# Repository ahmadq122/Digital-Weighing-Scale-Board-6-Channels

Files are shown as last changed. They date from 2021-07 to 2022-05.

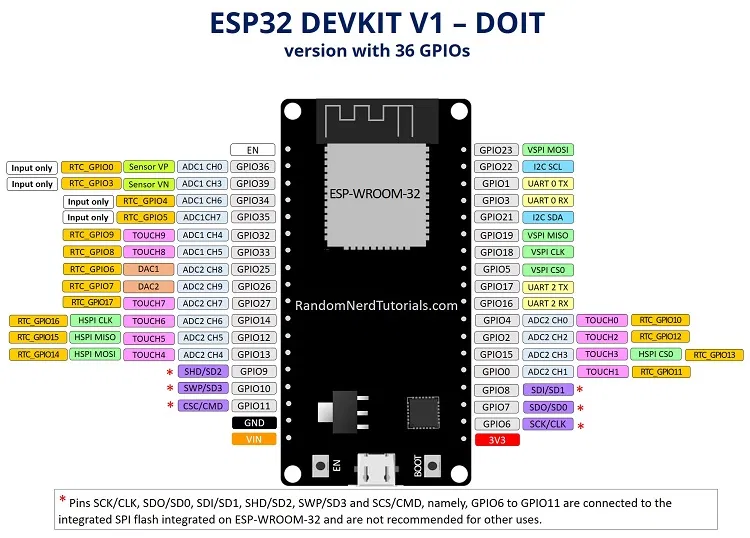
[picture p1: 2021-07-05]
pict/ESP32-DOIT-DEVKIT-V1-Board-Pinout-36-GPIOs-updated.png

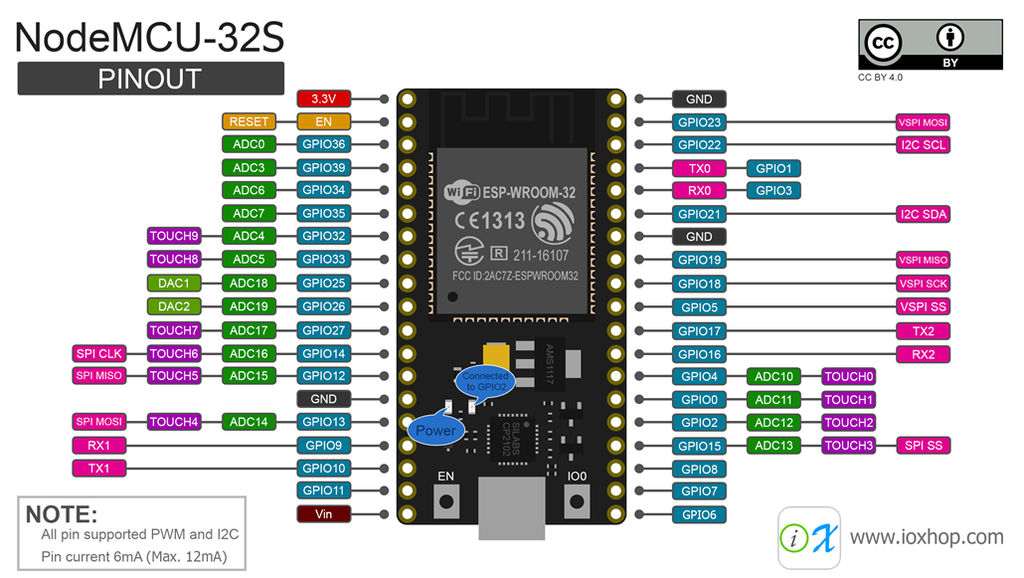
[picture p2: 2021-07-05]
pict/ESP-32S Pin.png

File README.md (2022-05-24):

# Digital-Weighing-Scale-Board-6-Channels
The board uses ESP32 Dev Board as the microcontroller with Nextion 3.2" LCD Touch as a User Interface, made in portable form, and easy to use. Real Time Operating System (FreeRTOS) was applied to get better code structure and device performance. Weighing can be performed on 6 different objects at the same time, with adjustable maximum weighing on each channel. Use 3 pcs of IC ADS1232 as an Analog to Digital Converter. Calibration sensor feature available, with a maximum of 8 calibration points. 3 data logging models are available, which are Local via Micro SD card, Serial RS232, and logging through ThingSpeak.

Code programming is done in IDE: Platform IO - Visual Studio Code Framework: Arduino

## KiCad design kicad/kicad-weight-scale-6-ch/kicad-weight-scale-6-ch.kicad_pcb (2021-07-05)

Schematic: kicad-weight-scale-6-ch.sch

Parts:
BT1: 18650 Li-ion; TerminalBlock_bornier-2_P5.08mm
BZ1: Buzzer; Buzzer_12x9.5RM7.6
C1: 220u; CP_Radial_D7.5mm_P2.50mm
C2: 100U; CP_Radial_D7.5mm_P2.50mm
D1, D2, D3: D_Schottky; D_SMA-SMB_Universal_Handsoldering
J1: Barrel_Jack_Switch; BarrelJack_Horizontal
J2, J6, J7, J8, J9: Conn_01x02; PinHeader_1x02_P2.54mm_Vertical
J3, J4, J5: Conn_01x04; PinHeader_1x04_P2.54mm_Vertical
Q1, Q2: Si4542DY; SOIC-8_3.9x4.9mm_P1.27mm
Q3: BSS138; SOT-23
R1, R2, R3: 10k; R_0805_2012Metric_Pad1.20x1.40mm_HandSolder
R4: 27k; R_0805_2012Metric_Pad1.20x1.40mm_HandSolder
R5, R6, R7, R10, R11: 1M; R_0805_2012Metric_Pad1.20x1.40mm_HandSolder
R8: 100k; R_0805_2012Metric_Pad1.20x1.40mm_HandSolder
R9: 1k; R_0805_2012Metric_Pad1.20x1.40mm_HandSolder
SW1: SW_Push; PinHeader_1x02_P2.54mm_Vertical
U1: TP-4056; Li-ion ic charger
U2: StepUpTo5V; Step up 5V
U3, U5, U7: WCMCU-ADS1232; wcmcu-ads1232
U4: ESPWROOM32; esp wroom 32 board
U6: DataLoggingBoard; Datalogging board
U8, U9, U10, U11, U12, U13: USB_Type_C; Type C Converter

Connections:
3V3: U3.10 (DVDD/1), U4.1, U5.10 (DVDD/1), U7.10 (DVDD/1)
5V: D2.2 (A), J9.1, Q2.4 (G), R5.2
A0_1: U3.13 (A0/8), U4.13
A0_2: U4.10, U5.13 (A0/8)
A0_3: U4.24, U7.13 (A0/8)
AINN1_1: U3.15 (AINN1/12), U8.4, U8.10
AINN1_2: U5.15 (AINN1/12), U10.4, U10.10
AINN1_3: U7.15 (AINN1/12), U12.4, U12.10
AINN2_1: U3.17 (AINN2/13), U9.4, U9.10
AINN2_2: U5.17 (AINN2/13), U11.4, U11.10
AINN2_3: U7.17 (AINN2/13), U13.4, U13.10
AINP1_1: U3.16 (AINP1/11), U8.3, U8.9
AINP1_2: U5.16 (AINP1/11), U10.3, U10.9
AINP1_3: U7.16 (AINP1/11), U12.3, U12.9
AINP2_1: U3.18 (AINP2/14), U9.3, U9.9
AINP2_2: U5.18 (AINP2/14), U11.3, U11.9
AINP2_3: U7.18 (AINP2/14), U13.3, U13.9
BUZZ: Q3.1 (G), R11.2, U4.29
CLKIN_1: J6.1, U3.14 (CLKIN/3)
CLKIN_2: J7.1, U5.14 (CLKIN/3)
CLKIN_3: J8.1, U7.14 (CLKIN/3)
DATA_1: U3.5 (24/~DRDY~/DOUT), U4.12
DATA_2: U4.9, U5.5 (24/~DRDY~/DOUT)
DATA_3: U4.23, U7.5 (24/~DRDY~/DOUT)
EN: J2.1, U4.2
GND: BT1.2 (-), C1.2, C2.2, J1.2, J1.3, J2.2, J3.4, J4.4, J5.4, J6.2, J7.2, J8.2, Q1.1 (S), Q3.2 (S), R5.1, R6.1, R7.2, R8.2, R10.2, R11.1, U1.3 (B-), U1.4 (OUT-), U1.5 (GND), U2.2, U2.4, U3.8 (17/AGND), U3.11 (DGND/2), U3.12 (TEMP/7), U4.14, U4.32, U4.38, U5.8 (17/AGND), U5.11 (DGND/2), U5.12 (TEMP/7), U6.2 (GND), U6.8 (CS), U7.8 (17/AGND), U7.11 (DGND/2), U7.12 (TEMP/7), U8.6, U8.7, U9.6, U9.7, U10.6, U10.7, U11.6, U11.7, U12.6, U12.7, U13.6, U13.7
MISO: U4.31, U6.6 (MISO)
MOSI: U4.37, U6.7 (MOSI)
unnamed: BZ1.2 (+), Q3.3 (D)
unnamed: D1.2 (A), Q2.5 (D), Q2.6 (D), R6.2
unnamed: D3.2 (A), R9.2, SW1.2
unnamed: J1.1, J9.2, U1.6 (5V)
unnamed: Q1.4 (G), Q1.7 (D), Q1.8 (D), R2.2
RXD0: J3.2, U4.34
RXD1: J4.2, U4.16
RXD2: J5.2, U4.27
SCK: U4.30, U6.5 (SCK)
SCL: U4.36, U6.4 (SCL)
SCLK_1: U3.6 (23/SCLK), U4.11
SCLK_2: U4.8, U5.6 (23/SCLK)
SCLK_3: U4.15, U7.6 (23/SCLK)
SDA: U4.33, U6.3 (SDA)
SPEED: U3.3 (21/SPEED), U4.26, U5.3 (21/SPEED), U7.3 (21/SPEED)
TXD0: J3.3, U4.35
TXD1: J4.3, U4.17
TXD2: J5.3, U4.28
VCC: BZ1.1 (-), C2.1, J3.1, J4.1, J5.1, R1.1, R3.1, U2.3, U3.1 (19/GAIN0), U3.2 (20/GAIN1), U3.7 (16/REFP), U3.9 (18/AVDD), U4.19, U5.1 (19/GAIN0), U5.2 (20/GAIN1), U5.7 (16/REFP), U5.9 (18/AVDD), U6.1 (5V), U7.1 (19/GAIN0), U7.2 (20/GAIN1), U7.7 (16/REFP), U7.9 (18/AVDD), U8.1, U8.12, U9.1, U9.12, U10.1, U10.12, U11.1, U11.12, U12.1, U12.12, U13.1, U13.12
VCC_1: C1.1, D1.1 (K), D2.1 (K), Q1.3 (1), R2.1, SW1.1
VCC_2: D3.1 (K), Q1.5 (D), Q1.6 (D), U2.1
VCC_B: BT1.1 (+), R4.1, U1.2 (B+)
VCC_B1: Q2.3 (1), U1.1 (OUT+)
VCC_B_SENSE: R4.2, R8.1, U4.6
VCC_CNTRL: Q1.2 (G), R7.1, U4.25
VCC_SENSE: R9.1, R10.1, U4.5
~CHRG: R1.2, U1.8 (~CHRG), U4.3
~PWDN: U3.4 (22/~PWDN~), U4.7, U5.4 (22/~PWDN~), U7.4 (22/~PWDN~)
~STDBY: R3.2, U1.7 (~STDBY), U4.4

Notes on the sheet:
add diode, and move vcc sens junction

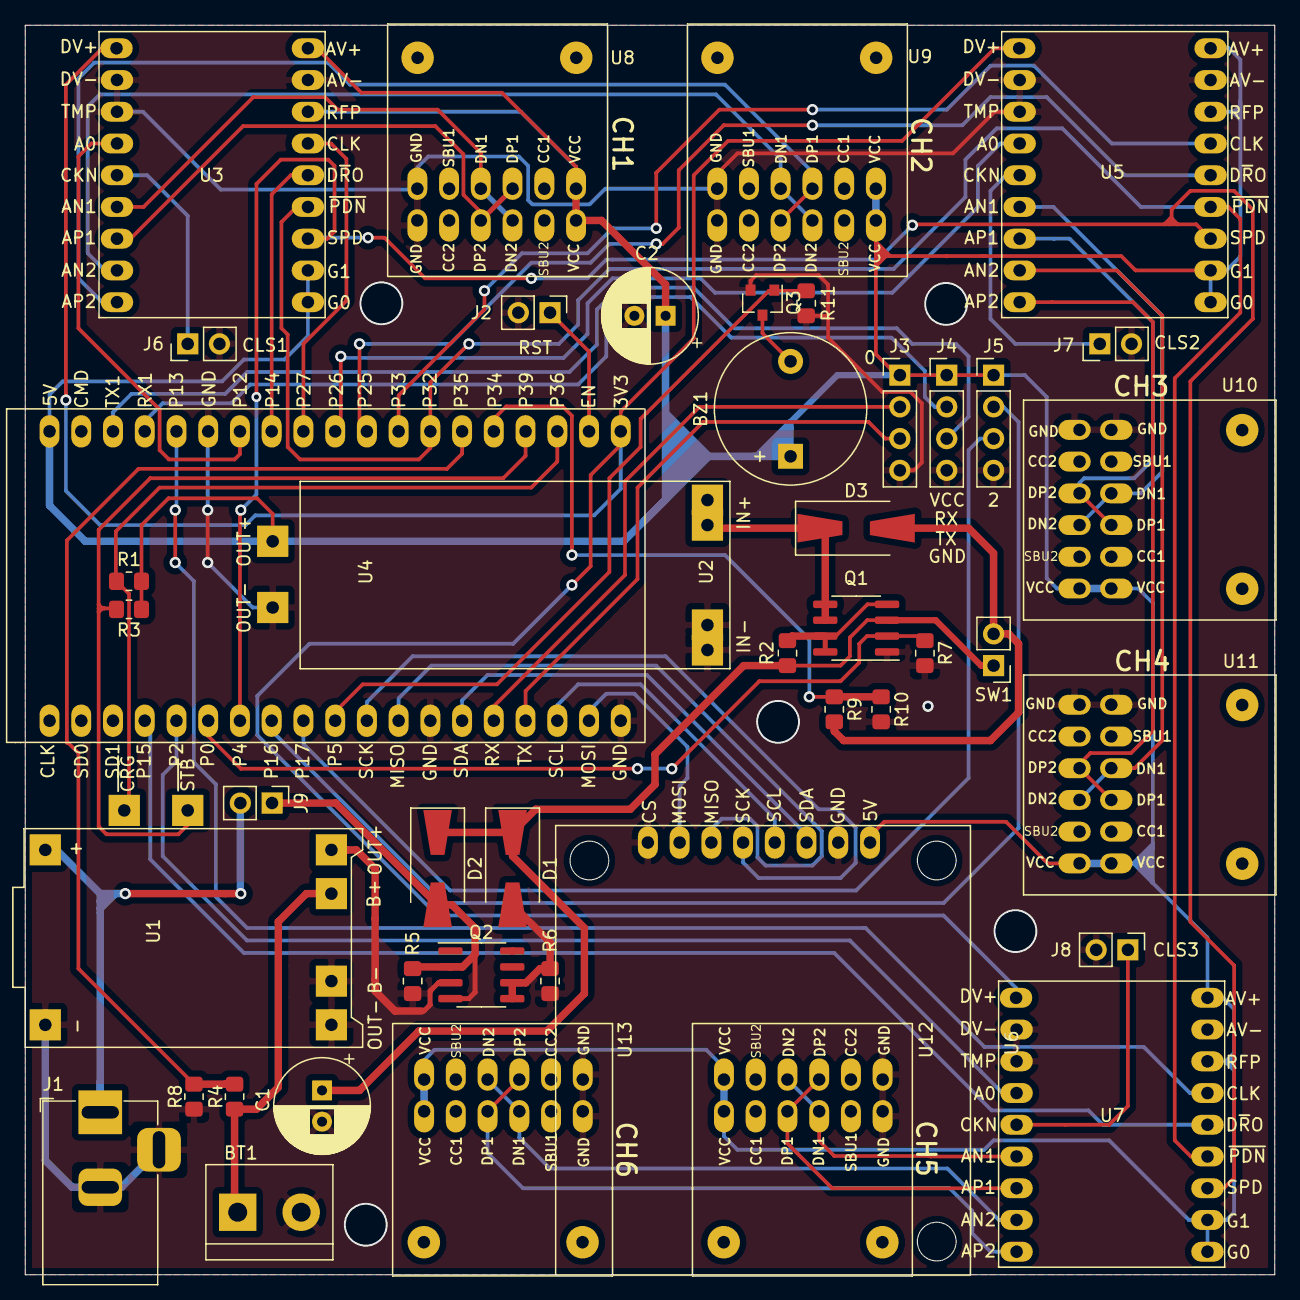
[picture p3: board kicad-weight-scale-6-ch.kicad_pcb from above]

Board: 2 copper layers, 100.0 x 100.0 mm, 44 parts (0 on the bottom side), 57 nets.

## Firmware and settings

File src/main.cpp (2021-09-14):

#include "StateMachine/StateMachine.h"
// #include "Nextion/Nextion.h"
#include "FlashMemory/FlashMemory.h"

StateMachine* state;

void setup()
{
  // put your setup code here, to run once:
  state->setup();
}

void loop()
{
  // put your main code here, to run repeatedly:

  uint8_t nextState = HOME;

  // MemoryFlash d;

  // Serial.println(String() + "uint8_t:" + sizeof(uint8_t));
  // Serial.println(String() + "uint16_t:" + sizeof(uint16_t));
  // Serial.println(String() + "uShort:" + sizeof(unsigned short));
  // Serial.println(String() + "uint32_t:" + sizeof(uint32_t));
  // Serial.println(String() + "uint:" + sizeof(unsigned int));
  // Serial.println(String() + "uLong:" + sizeof(unsigned long));
  // Serial.println(String() + "float:" + sizeof(float));
  // Serial.println(String() + "double:" + sizeof(double));
  // Serial.println(String() + "uint64_t:" + sizeof(uint64_t));
  // Serial.end();
  // Serial.begin(115200);
  // delay(1000);
  // uint8_t sizeLeft = MEMORY_SIZE - sizeof(d.flash);
  // uint16_t size = sizeof(d.flash);
  // Serial.println(size);
  // Serial.println(String() + "Free memory: " + sizeLeft + " bytes");

  while (true)
  {
    nextState = state->homeScreen();

    switch (nextState)
    {
    case NETWORK:
      state->networkSettings();
      break;
    case SETTINGS:
      state->settings();
      break;
    case UNITS:
      state->measurementUnits();
      break;
    case DATALOG:
      state->datalogSettings();
      break;
    default:
      break;
    }
  }
}

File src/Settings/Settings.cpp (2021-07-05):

#include "Settings.h"
#include "Nextion/Nextion.h"
#include "DebugSerial/DebugSerial.h"
#include "FlashMemory/FlashMemory.h"
#include "Time/MyTime.h"
#include "RTOS/RTOS.h"
#include "ADC/ADS1232.h"
#include "PictureListID.h"
#include "Utility/Utility.h"
#include "PinMap.h"

void Settings::mainMenu(void)
{
    bool button[8];
    bool adcRateValue = data.getSpeedRate();
    bool mute = data.getBuzzerMute();
    uint8_t menuPage = 0;

start:

    if (menuPage == 0)
    {
        hmi.showPage("settings");
        hmi.waitForPageRespon();
    }
    else
    {
        hmi.showPage("settings1");
        hmi.waitForPageRespon();
        if (adcRateValue && data.getSpeedRate())
        {
            hmi.setIntegerToNextion("b0.picc", Settings1_Menu_Normal_Btn);
            hmi.setIntegerToNextion("b0.picc2", Settings1_Menu_Prs_Btn);
        }
        else
        {
            if (adcRateValue != data.getSpeedRate())
                adcRateValue = data.getSpeedRate();
            hmi.setIntegerToNextion("b0.picc", Settings11_Menu_Normal_Btn);
            hmi.setIntegerToNextion("b0.picc2", Settings11_Menu_Prs_Btn);
        }
        if (mute && data.getBuzzerMute())
        {
            hmi.setIntegerToNextion("b2.picc", Settings11_Menu_Normal_Btn);
            hmi.setIntegerToNextion("b2.picc2", Settings11_Menu_Prs_Btn);
        }
        else
        {
            if (mute != data.getBuzzerMute())
                mute = data.getBuzzerMute();
            hmi.setIntegerToNextion("b2.picc", Settings1_Menu_Normal_Btn);
            hmi.setIntegerToNextion("b2.picc2", Settings1_Menu_Prs_Btn);
        }
    }
    printDebugln("Settings page opened");

    while (true)
    {
        // hmi.serialEvent_2();
        if (hmi.getExitPageFlag())
        {
            printDebugln("Exit Settings page");
            return;
        }
        for (int i = 0; i < 8; i++)
        {
            button[i] = hmi.getDataButton(i);
            if (button[i])
            {
                switch (i)
                {
                case 0:
                    if (menuPage == 0)
                    {
                        printDebugln("Timezone page opened");
                        timeZone();
                    }
                    else if (menuPage == 1)
                    {
                        printDebugln("ADC Rate value changed");
                        adcRateValue = !adcRateValue;
                        data.setSpeedRate(adcRateValue);
                        hmi.showSavingBarAnimation(1000);
                    }
                    break;
                case 1:
                    printDebugln("Brightness page opened");
                    if (menuPage == 0)
                        brightness();
                    else if (menuPage == 1)
                    {
                        hmi.setVisObjectNextion("q0", true);
                        hmi.setVisObjectNextion("b8", true);
                        hmi.setVisObjectNextion("b9", true);

                        while (true)
                        {
                            if (hmi.getExitPageFlag())
                            {
                                printDebugln("Exit Settings page");
                                return;
                            }
                            if (hmi.getDataButton(8))
                            {
                                break;
                            }
                            if (hmi.getDataButton(9))
                            {
                                if (data.resetDefault())
                                    hmi.showSavingBarAnimation(250);
                                break;
                            }
                        }

                        hmi.setVisObjectNextion("b8", false);
                        hmi.setVisObjectNextion("b9", false);
                        hmi.setVisObjectNextion("q0", false);
                        hmi.flushAvailableButton();
                    }
                    break;
                case 2:
                    printDebugln("Maximum page opened");
                    if (menuPage == 0)
                        setLimit();
                    else
                    {
                        mute = !mute;
                        data.setBuzzerMute(mute);
                        hmi.showSavingBarAnimation(500);
                    }
                    break;
                case 3:
                    printDebugln("Set time and date");
                    if (menuPage == 0)
                        timeAndDate();
                    break;
                case 4:

                    if (menuPage == 0)
                    {
                        printDebugln("Debug page opened");
                        debugMenu();
                    }
                    else
                    {
                        hmi.showPage("off");
                        hmi.waitForPageRespon();
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

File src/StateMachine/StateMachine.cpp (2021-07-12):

#include <Arduino.h>
#include "StateMachine.h"
#include "FlashMemory/FlashMemory.h"
#include "Nextion/Nextion.h"
#include "DebugSerial/DebugSerial.h"
#include "Network/Network.h"
#include "Time/MyTime.h"
#include "MicroSD/MicroSD.h"
#include <HTTPClient.h>
#include "Settings/Settings.h"
#include "ADC/ADS1232.h"
#include "RTOS/RTOS.h"
#include "Datalogger/Datalogger.h"
#include "PinMap.h"
#include "PictureListID.h"
#include "Utility\Utility.h"

/*****************************************************************************
 *******************************ESP32S-PIN************************************
 *                  ---------------------------------
 *              ---|3.3V     ---__---__-----      GND|---
 *              ---|EN/RST  |            | |       23|---VSPI_MOSI
 *            AI---|36       _______________       22|---SCL
 *            AI---|39      |               |       1|---TX0
 *            AI---|34      | ESP-WROOM-32  |       3|---RX0
 *            AI---|35      |               |      21|---SDA
 *           DIO---|32      |               |     GND|---
 *           DIO---|33      |               |      19|---VSPI_MISO
 *           DIO---|25      |_______________|      18|---VSPI_SCK
 *           DIO---|26                              5|---DIO
 *           DIO---|27                             17|---TX2
 *           DIO---|14                             16|---RX2
 *           DIO---|12                             -4|---DIO
 *              ---|GND                            -0|---DIO
 *           DIO---|13                              2|---DIO
 *           RX1---|9                              15|---DIO
 *           TX1---|10           _______            8|---SD1*
 *      *CSC/CMD---|11   ___    |       |    ____   7|---SD0*
 *              ---|Vin |EN |   |       |   |BOOT|  6|---SCK/CLK*
 *                  ------------|_______|------------
 * 
 *          *Pins are connected to the integrated SPI Flash integrated on
 *           ESP-32 and are not recommended for other uses.
******************************************************************************/

// 36,//can't be used as output pin
// 39,////can't be used as output pin
// 34,//can't be used as output pin
// 35,//can't be used as output pin
// 9,
// 10,
// 11,6,7,8
// uint8_t pin[10] = {
//     12,
//     13,
//     15,
//     2,
//     32,
//     33,
//     25,
//     26,
//     27,
//     14};

void StateMachine::setup(void)
{
    uint8_t powerUpButtonWait = 2;
    bool flashBegin = false;
    uint8_t counter = 0;

    pinMode(Pin_VCC_Control, OUTPUT);
    pinMode(Pin_Buzzer, OUTPUT);
    digitalWrite(Pin_VCC_Control, 0);
    digitalWrite(Pin_Buzzer, 0);

    while (powerUpButtonWait > 0)
    {
        delay(1000);
        powerUpButtonWait--;
    }

    Serial.begin(115200);
    NexSerial.begin(115200);
    while (!NexSerial)
        ;
    hmi.showPage("start");
    //waiting for Nextion page ready
    while (!hmi.getWaitingEndSignal())
    {
        hmi.serialEvent_2();
        delay(100);
        if (++counter > 10)
        {
            hmi.showPage("start"); //call back start page if still no respons from LCD
            counter = 0;
        }
    }
    Serial.end();

    rtos.updateStartProgressBar(5);
    while (flashBegin == false)
    {
        flashBegin = initFlash(MEMORY_SIZE);
        delay(200);
    }
    delay(10);

    rtos.updateStartProgressBar(5);
    if (data.getDebugMode())
    {
        Serial.begin(data.getBaudrateSerial(debugging));
        while (!Serial)
            ;
        digitalWrite(Pin_VCC_Control, 0);
    }
    else
        digitalWrite(Pin_VCC_Control, 1);
    LogSerial.begin(data.getBaudrateSerial(logging));
    while (!LogSerial)
        ;

    rtos.updateStartProgressBar(10);
    ads.begin();
    rtos.setup();
    net.setup();
    initTime();
    rtos.updateStartProgressBar(10);
    hmi.init();
    card.setup();
    // initSDCard();
    while (rtos.startProgressBar < 100)
    {
        printDebugln(String() + "Progress: " + rtos.startProgressBar + " %");
        rtos.updateStartProgressBar(5);
        delay(50);
    }

    digitalWrite(Pin_Buzzer, 1);
    delay(100);
    digitalWrite(Pin_Buzzer, 0);
}

bool StateMachine::initTime(void)
{
    mtime.initOffset(data.getTimezone());
    return mtime.tBegin();
}

bool StateMachine::initFlash(uint16_t memory)
{
    if (memory > MEMORY_SIZE)
        return false;
    return data.begin(memory);
}

// void StateMachine::initSDCard(void)
// {
//     card.setup();
// }

/******************
 * List of Button at HomeScreen
 * 0) Network
 * 1) Settings
 * 2) Measurement Units
 * 3) Data logger
 * 4) EN/DIS Channel 1
 * 5) EN/DIS Channel 2
 * 6) EN/DIS Channel 3
 * 7) EN/DIS Channel 4
 * 8) EN/DIS Channel 5
 * 9) EN/DIS Channel 6
 * 10) Tare Channel 1
 * 11) Tare Channel 2
 * 12) Tare Channel 3
 * 13) Tare Channel 4
 * 14) Tare Channel 5
 * 15) Tare Channel 6
*/
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

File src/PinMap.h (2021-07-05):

#pragma once

#define Pin_PowerDown   32
#define Pin_SCLK_ADS2   33
#define Pin_SCLK_ADS1   27
#define Pin_SCLK_ADS3   13
#define Pin_DOUT_ADS2   25
#define Pin_DOUT_ADS1   14
#define Pin_DOUT_ADS3   15
#define Pin_A0_ADS2     26
#define Pin_A0_ADS1     12
#define Pin_A0_ADS3     2

#define Pin_Speedrate   4

#define Pin_VBat_Sense  35
#define Pin_Buzzer      5

#define Pin_VCC_Sense   34
#define Pin_VCC_Control 0

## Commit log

2021-03-28 Remove Interrupt Timer, applied FreeRTOS instead
2021-03-28 Auto dim screen, store brightness, store index baudrate, fix bug open page, fix stack overflow Task_01
    [FlashMemory.cpp, FlashMemory.h, Nextion.cpp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]
2021-03-28 fix bug: can't set the brightness at start up
    [Nextion.cpp, RTOS.h]
2021-03-28 Send auto dim once to nextion after auto dim timer achieved
2021-03-29 printDebug, put ads1232 data reading into Task_04, Task_05, and Task_06 to be run independently
2021-04-02 Update StartProgressBar, Single PWDN pin, Disable auto create data logger at setup(), Backend Zero Sensor
2021-04-03 Fix POint Calibrationt Page
    [FlashMemory.cpp, FlashMemory.h, Settings.cpp]
2021-04-11 Update Kicad, PinMap, Utility
    [kicad-weight-scale-6-ch.kicad_pcb, kicad-weight-scale-6-ch.sch]
2021-04-18 update PCB deisgn
    [kicad-weight-scale-6-ch-B_Cu.gbl, kicad-weight-scale-6-ch-B_Fab.gbr, kicad-weight-scale-6-ch-B_Mask.gbs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]
2021-05-17 Update nextion-esp32dws6chwl_ench.HMI, kicad-weight-scale-6-ch-cache.lib, and 6 more files...
    [kicad-weight-scale-6-ch.kicad_pcb, kicad-weight-scale-6-ch.sch]
2021-05-18 Update nextion-esp32dws6chwl_ench.HMI, PictureListID.h, and 2 more files...
2021-05-20 Update nextion-esp32dws6chwl_ench.HMI, Settings.cpp, and 4 more files...
2021-05-20 Update nextion-esp32dws6chwl_ench.HMI, Datalogger.cpp, and 6 more files...
2021-05-23 Update nextion-esp32dws6chwl_ench.HMI, Datalogger.cpp, and 7 more files...
2021-05-30 Update settings.json, nextion-esp32dws6chwl_ench.HMI, and 15 more files...
2021-06-02 Update settings.json, nextion-esp32dws6chwl_ench.HMI, and 10 more files...
2021-06-07 Update nextion-esp32dws6chwl_ench.HMI, ADS1232.cpp, and 7 more files...
2021-06-19 Update nextion-esp32dws6chwl_ench.HMI, kicad-weight-scale-6-ch.kicad_pcb, and 20 more files...
    [kicad-weight-scale-6-ch.kicad_pcb, kicad-weight-scale-6-ch.sch]
